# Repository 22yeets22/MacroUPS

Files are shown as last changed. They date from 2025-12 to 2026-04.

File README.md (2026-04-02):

<h1 align="center">
  MacroUPS
  <br>
</h1>

<h4 align="center">
<i>A totally awesome uninterruptible power supply for high speed charging!</i>
</h4>
<br>

### Specs

- 180 Wh LiFePO4 battery - charges an iPhone 16 13 times from 0% to 100%
- 250 watts usb output continuous
- 4 fast charge usb-c ports
- 4 usb-a ports (2 fast charge, 2 slow)
- instantaneous switchover time on power outage

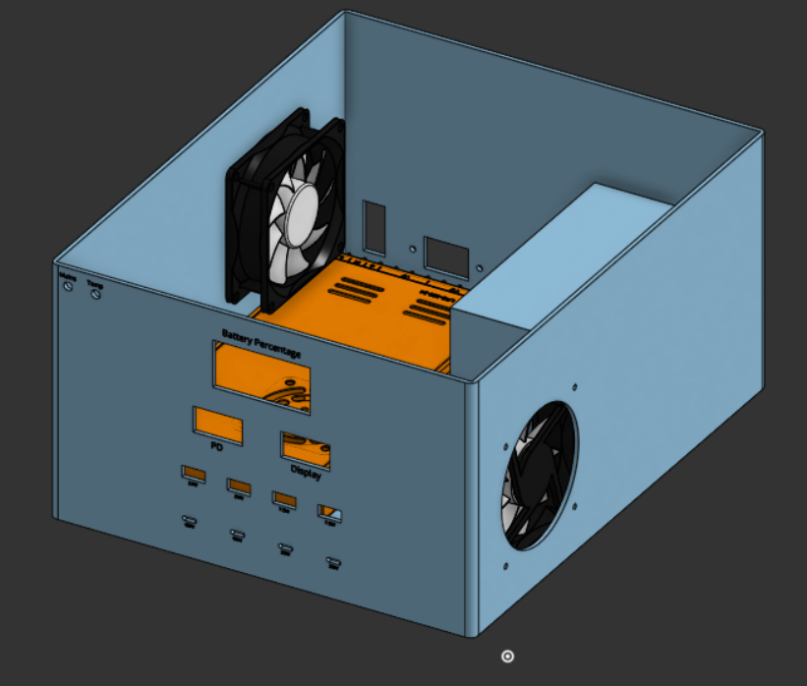
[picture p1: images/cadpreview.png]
CAD preview version 3

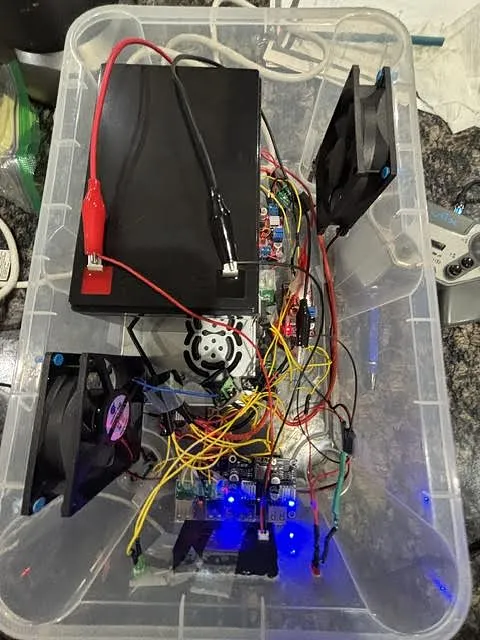
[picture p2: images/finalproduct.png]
Final Product


### Motivation

In our house, we currently charge all our devices in one place, and there aren't enough power outlets. This UPS also acts as backup power in case of an outage, so we can still charge our devices for long after the power is out.

## Parts List

### Power

- 1x of `14awg Wire 30ft`, TYPE 15ft 14awg: [link](https://www.amazon.com/gp/product/B0D969PF5C/) – PRICE $9.98
- 1x of `Power Supply Cable 3-Prong 1.2m`, TYPE USA: [link](https://www.aliexpress.com/item/3256807060355465.html) – PRICE $3.49
- 1x of `IEC320 C14/C13 Panel Socket`, TYPE Type 4: [link](https://www.aliexpress.com/item/3256808473935736.html) – PRICE $1.33
- 1x of `24V 7Ah LiFePO4 Rechargeable Battery with BMS`, TYPE 24V / 7Ah: [link](https://www.amazon.com/gp/product/B0DSRT3BB8/) – PRICE $42.99
- 1x of `MEAN WELL LRS-350-24`, TYPE N/A: [link](https://www.amazon.com/gp/product/B013ETVO12/) – PRICE $28.54

### Power Delivery

- 1x of `PD65W fast charging module (Type-C)`, TYPE 4pcs: [link](https://www.aliexpress.com/item/3256806830457021.html) – PRICE $4.19
- 1x of `PD45W fast charging module (Type-C)`, TYPE 45W: [link](https://www.aliexpress.com/item/3256807318962557.html) – PRICE $1.99
- 2x of `PD30W fast charging module (Type-C)`, TYPE 30W: [link](https://www.aliexpress.com/item/3256807318962557.html) – PRICE $1.95
- 1x of `USB-A breakout female board`, TYPE 5PCS: [link](https://www.aliexpress.com/item/3256807147268432.html) – PRICE $1.24
- 1x of `USB-A QC2.0/3.0 buck converter module`, TYPE 2 Channel: [link](https://www.aliexpress.com/item/3256809395236306.html) – PRICE $1.99
- 4x of `120W USB-C to USB-C fast charging cable`, TYPE Black C-C/2m: [link](https://www.aliexpress.com/item/3256807024111085.html) – PRICE $2.79
- 4x of `120W USB-C to USB-A fast charging cable`, TYPE Black A-C/2m: [link](https://www.aliexpress.com/item/3256807024111085.html) – PRICE $2.21

### Modules

- 1x of `DC-DC adjustable buck converter XL4015`, TYPE HW-083B 4pcs: [link](https://www.aliexpress.com/item/3256806491709950.html) – PRICE $5.07
- 1x of `Battery capacity indicator voltmeter`, TYPE Color Screen/CHINA: [link](https://www.aliexpress.com/item/3256804198482360.html) – PRICE $4.46

#### The Custom Ideal Diode Module (5x) - Order Total (for 5x): $29.12

Check the [ideal diode folder](https://github.com/22yeets22/MacroUPS/tree/main/Ideal%20Diode) for specific BOM, gerber, pickandplace, as well as source files + images.

> [!IMPORTANT]
> There is a folder named `DONOTUSE` with the old versions. The mosfet is the wrong direction in those versions, so please don't use them unless you like expensive paperweights.

Motivation:

- Almost all cheap ideal diode modules commonly found on AliExpress use the XL74610. However, it has voltage drops every half-second because it is groundless and must recharge its capacitor. This is bad for my application, since it would cause voltage fluctuations and constant switching between battery and mains.
- Handles **30a** with big heatsinks on both sides and maybe a thicker copper pour or copper wires on VIN and VOUT)
- Voltage range is up to **40V** limited by the MOSFET.
- 125 C max operating temperature (by components minimum temp), but please keep it cooler than that.

| Schematic | PCB | 3D View |
| --- | --- | --- |
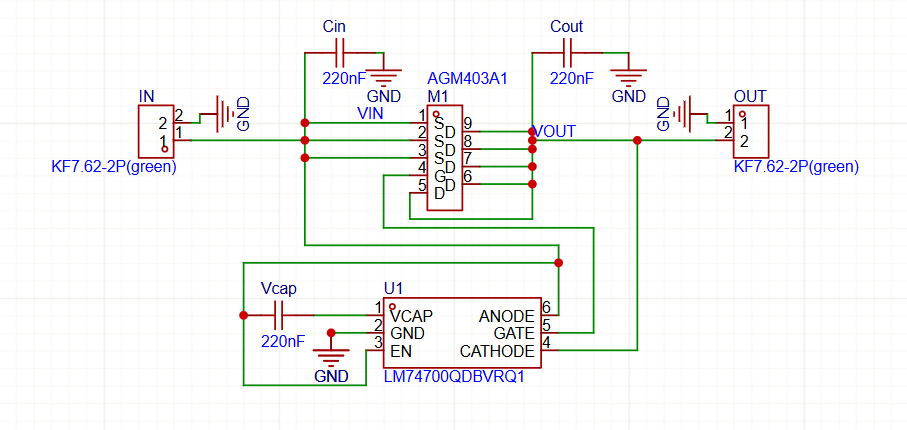
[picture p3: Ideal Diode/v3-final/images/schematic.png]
Schematic
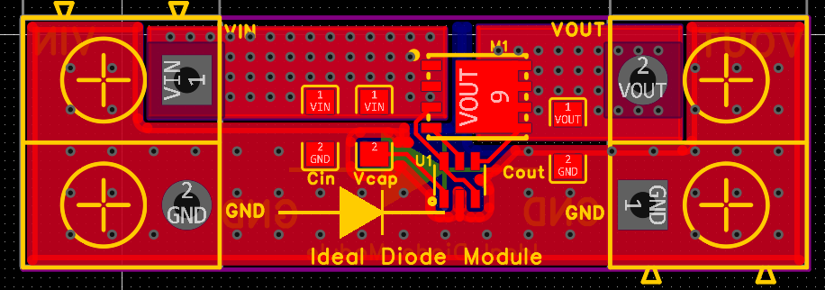
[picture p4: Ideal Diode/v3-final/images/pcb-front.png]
PCB
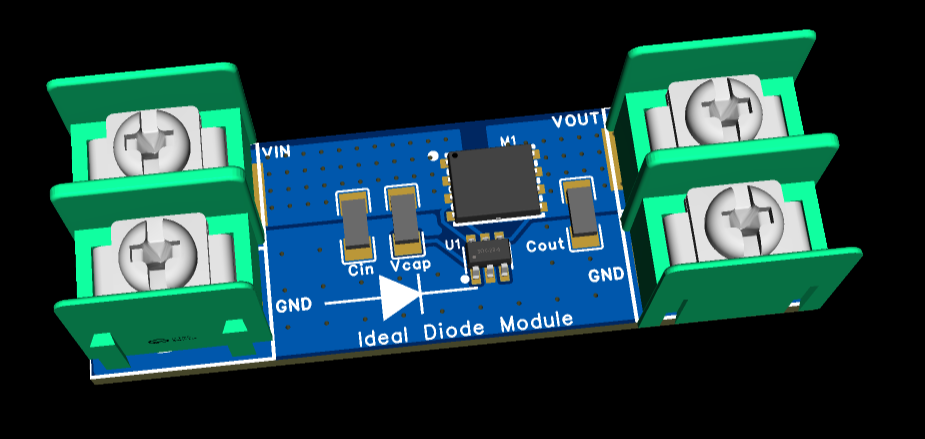
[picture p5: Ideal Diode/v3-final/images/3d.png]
3D
|  |  |  |

### Switches + Fuses

- 1x of `Rocker switch ON-OFF`, TYPE Red 2Pin: [link](https://www.aliexpress.com/item/2255800661582532.html) – PRICE $0.76
- 2x of `SPST waterproof toggle switch`, TYPE N/A: [link](https://www.aliexpress.com/item/3256808459598008.html) – PRICE $2.89
- 2x of `Circuit breaker switch fuse`, TYPE 10A/Other: [link](https://www.aliexpress.com/item/3256805757815979.html) – PRICE $1.63
- 1x of `Circuit breaker switch fuse`, TYPE 15A/Other: [link](https://www.aliexpress.com/item/3256805757815979.html) – PRICE $1.89

### Cooling

- 2x of `12V DC cooling fan`, TYPE 8025/12V: [link](https://www.aliexpress.com/item/3256806120222119.html) – PRICE $3.59
- 3x of `Thermal switch temperature sensor 40C/H`, TYPE 40C/H (Normally Open): [link](https://www.aliexpress.com/item/2251832786193672.html) – PRICE $1.33
- 1x of `Aluminum heatsink 15x15x15mm`, TYPE 15x15x15mm: [link](https://www.aliexpress.com/item/3256803892794950.html) – PRICE $4.38
- 1x of `Aluminum heatsink 8.8x8.8x5mm`, TYPE 8.8x8.8x5mm: [link](https://www.aliexpress.us/item/2251832663311102.html) – PRICE $2.29

## Wiring Diagram

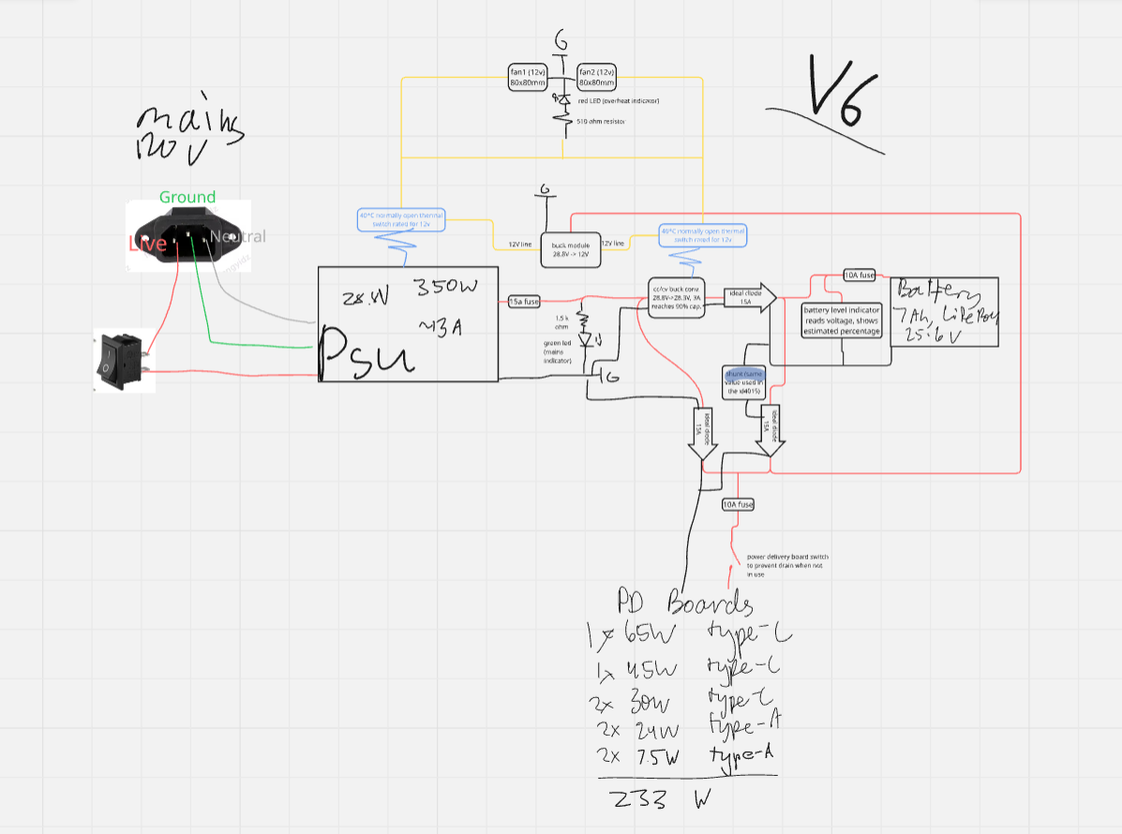
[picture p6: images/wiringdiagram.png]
Wiring diagram version 5


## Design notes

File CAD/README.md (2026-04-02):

## CAD Readme

Quick note, the `MacroUPS3.step` file is the main version. The `USBC Stand.step` file is a file just to hold the usb-c modules in place. The assembly likely differs for everyone, so it may not even be used.

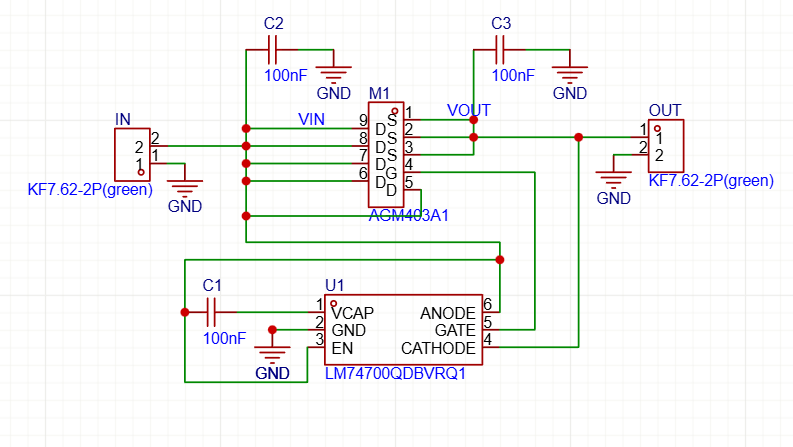
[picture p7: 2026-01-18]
Ideal Diode/DONOTUSE/v2/images/schematic.png

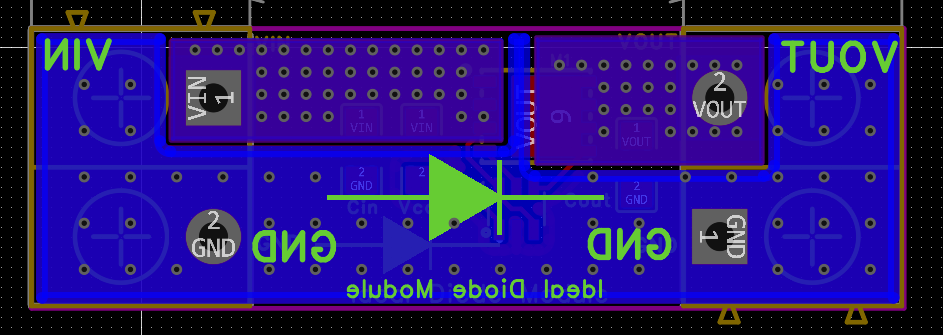
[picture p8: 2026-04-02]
Ideal Diode/v3-final/images/pcb-back.png

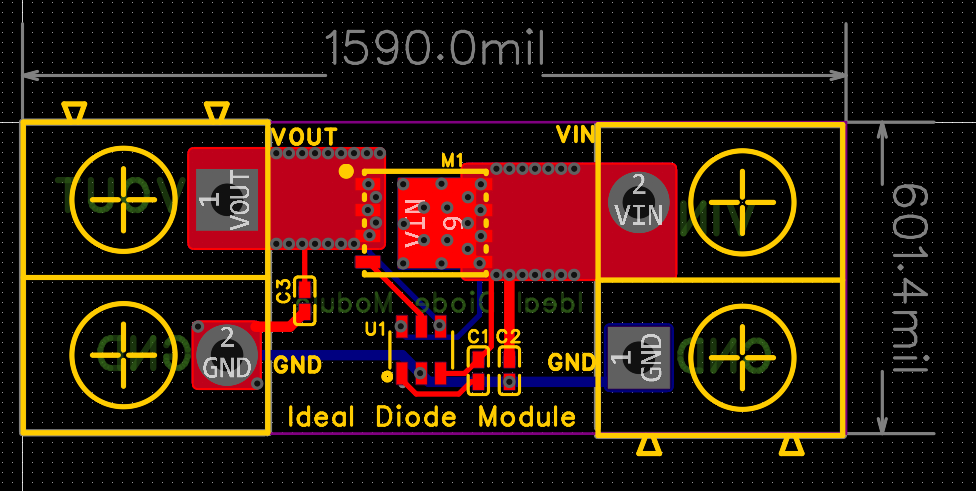
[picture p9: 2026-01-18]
Ideal Diode/DONOTUSE/v2/images/pcb.png

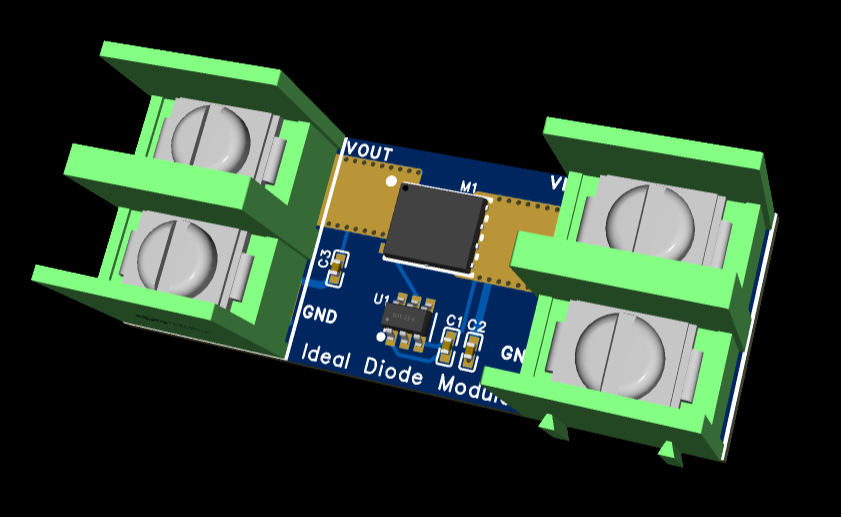
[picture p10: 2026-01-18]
Ideal Diode/DONOTUSE/v2/images/3d.png

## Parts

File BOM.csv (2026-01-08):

Category | Quantity | Part Name | Type | Link | Price
Power | 1 | 14awg Wire 30ft | 15ft 14awg | https://www.amazon.com/gp/product/B0D969PF5C/ | $9.98
Power | 1 | Power Supply Cable 3-Prong 1.2m | USA | https://www.aliexpress.com/item/3256807060355465.html | $3.49
Power | 1 | IEC320 C14/C13 Panel Socket | Type 4 / China Mainland | https://www.aliexpress.com/item/3256808473935736.html | $1.33
Power | 1 | 24V 7Ah LiFePO4 Rechargeable Battery with BMS | 24V / 7Ah | https://www.amazon.com/gp/product/B0DSRT3BB8/ | $42.99
Power | 1 | MEAN WELL LRS-350-24 | N/A | https://www.amazon.com/gp/product/B013ETVO12/ | $28.54
Power Delivery | 1 | PD65W fast charging module (Type-C) | 4pcs | https://www.aliexpress.com/item/3256806830457021.html | $4.19
Power Delivery | 1 | PD45W fast charging module (Type-C) | 45W | https://www.aliexpress.com/item/3256807318962557.html | $1.99
Power Delivery | 2 | PD30W fast charging module (Type-C) | 30W | https://www.aliexpress.com/item/3256807318962557.html | $1.95
Power Delivery | 1 | USB-A breakout female board | 5PCS | https://www.aliexpress.com/item/3256807147268432.html | $1.24
Power Delivery | 1 | USB-A QC2.0/3.0 buck converter module | 2 Channel | https://www.aliexpress.com/item/3256809395236306.html | $1.99
Power Delivery | 3 | 120W USB-C to USB-C fast charging cable | Black C-C/2m | https://www.aliexpress.com/item/3256807024111085.html | $2.79
Power Delivery | 4 | 120W USB-C to USB-A fast charging cable | Black A-C/2m | https://www.aliexpress.com/item/3256807024111085.html | $2.21
Power Delivery | 1 | NNBILI 100W USB C/A charging cable | 100W USB C cable/1m | https://www.aliexpress.com/item/3256806737244284.html | $2.67
Modules | 1 | DC-DC adjustable buck converter XL4015 | HW-083B 4pcs | https://www.aliexpress.com/item/3256806491709950.html | $5.07
Modules | 1 | Battery capacity indicator voltmeter | Color Screen/CHINA | https://www.aliexpress.com/item/3256804198482360.html | $4.46
Modules | 5 | CUSTOM Ideal Diode Module | N/A | https://github.com/22yeets22/MacroUPS/tree/main/Ideal%20Diode | $29.12
Switches + Fuses | 1 | Rocker switch ON-OFF | Red 2Pin | https://www.aliexpress.com/item/2255800661582532.html | $0.76
Switches + Fuses | 2 | SPST waterproof toggle switch | N/A | https://www.aliexpress.com/item/3256808459598008.html | $2.89
Switches + Fuses | 2 | Circuit breaker switch fuse | 10A/Other | https://www.aliexpress.com/item/3256805757815979.html | $1.63
Switches + Fuses | 1 | Circuit breaker switch fuse | 15A/Other | https://www.aliexpress.com/item/3256805757815979.html | $1.89
Cooling | 2 | 12V DC cooling fan | 8025/12V | https://www.aliexpress.com/item/3256806120222119.html | $3.59
Cooling | 3 | Thermal switch temperature sensor 40C/H | 40C/H (Normally Open) | https://www.aliexpress.com/item/2251832786193672.html | $1.33
Cooling | 1 | Aluminum heatsink 15x15x15mm | 15x15x15mm | https://www.aliexpress.com/item/3256803892794950.html | $4.38
Cooling | 1 | Aluminum heatsink 8.8x8.8x5mm | 8.8x8.8x5mm | https://www.aliexpress.us/item/2251832663311102.html | $2.29

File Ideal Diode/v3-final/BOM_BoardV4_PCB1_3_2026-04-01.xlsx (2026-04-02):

No. | Quantity | Comment | Designator | Footprint | Value | Manufacturer Part | Manufacturer | Supplier Part | Supplier
1 | 3 | 220nF | Cin,Cout,Vcap | C1206 | 220nF | CC1206KKX7R0BB224 | YAGEO(国巨) | C113892 | LCSC
2 | 2 | KF7.62-2P(green) | IN,OUT | CONN-TH_2P-P7.62_KEFA_KF7.62-2P |  | KF7.62-2P(green) | KEFA(科发) | C5173665 | LCSC
3 | 1 | AGM403A1 | M1 | DFN-8_L5.8-W4.9-P1.27-LS6.0-BL-1 |  | AGM403A1 | AGMSEMI(芯控源) | C5184861 | LCSC
4 | 1 | LM74700QDBVRQ1 | U1 | SOT-23-6_L2.9-W1.6-P0.95-LS2.8-BL |  | LM74700QDBVRQ1 | TI(德州仪器) | C2941042 | LCSC

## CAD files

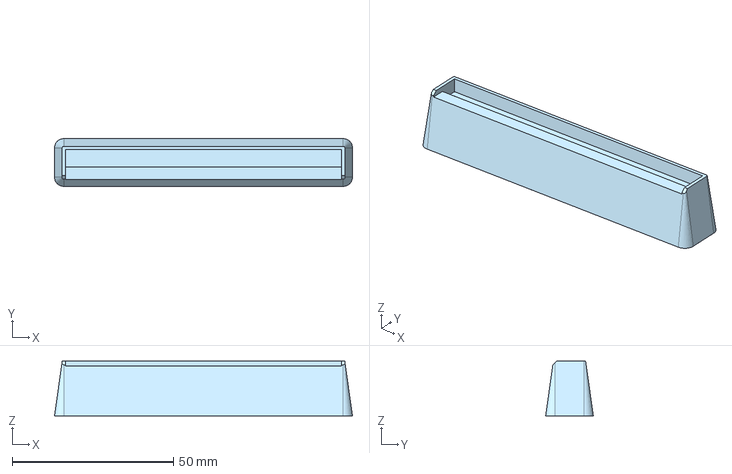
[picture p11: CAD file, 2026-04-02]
CAD/USBC Stand.step
92.3 x 14.8 x 17.0 mm

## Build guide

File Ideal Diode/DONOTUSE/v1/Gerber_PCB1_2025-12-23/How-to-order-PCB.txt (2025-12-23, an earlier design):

How to Order PCB

Please refer to:
https://prodocs.easyeda.com/en/pcb/order-order-pcb/index.html

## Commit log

2025-12-14 add cad
2025-12-14 Rename Screenshot 2025-12-14 135559.png to wiringdiagram.png
2025-12-15 Add wiring diagram to README
    Added a wiring diagram section with an image to the README.
2025-12-15 Revise BOM with new categories and parts
    Updated BOM.csv to include new categories and additional parts with details.
    [BOM.csv]
2025-12-15 Fix BOM.csv formatting and header alignment
    [BOM.csv]
2025-12-18 New bom
    [BOM.csv]
2025-12-18 Rename Screenshot 2025-12-17 204821.png to wiringdiagram.png
2025-12-18 Add USB-A breakout board to parts list
2025-12-18 add usb-a breakout board (fix formatting)
    Added a parts list for the MacroUPS project.
2025-12-18 new cad files
2025-12-18 Revise USB buck converter module type in README
    Updated parts list to reflect changes in USB buck converter module type.
2025-12-18 Modify USB QC2.0/3.0 buck converter module details (fix bom)
    Updated the USB QC2.0/3.0 buck converter module from 4 Channel to 2 Channel.
    [BOM.csv]
2025-12-18 add ideal diode pcb stuff
    [BOM.xlsx, PickAndPlace.xlsx]
2025-12-18 Update ideal diode module entry in BOM.csv
    [BOM.csv]
2025-12-18 Add Custom Ideal Diode Module section to README
    Added section for the Custom Ideal Diode Module with links.
2025-12-23 Update link text for ideal diode module section
2025-12-23 Rename Screenshot 2025-12-23 102950.png to schematic.png
2025-12-23 Revise power delivery module specifications
    Updated the list of power delivery modules in the README.
2025-12-23 update ideal diode gerber, pickandplace, bom, updated BOM.csv, added ideal diode source files, updated readme with also schematic
    [BOM.csv, BOM.xlsx, BOM_Board1_PCB1_2025-12-23.xlsx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]
2025-12-23 Update quantity for CUSTOM IDEAL DIODE MODULE
    [BOM.csv]
2025-12-23 Update Custom Ideal Diode Module section in README
2025-12-23 Uploaded step CAD
2025-12-23 Update quantity and order total for ideal diode module
2025-12-23 Add category and price columns to BOM.csv
    Updated BOM.csv to include category and price information for each part.
    [BOM.csv]
2025-12-23 Revise order total for Custom Ideal Diode Module
    Updated the order total for the Custom Ideal Diode Module section.
2025-12-23 add folder for ideal diode images
2025-12-23 unzip gerber???
    [Drill_PTH_Through.DRL, Drill_PTH_Through_Via.DRL, Gerber_BoardOutlineLayer.GKO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]
2026-01-01 Update parts list and add motivation for ideal diode module
    Added new power supply and socket details to the parts list, along with motivation for the custom ideal diode module.
2026-01-01 Enhance README with motivation for ideal diode module
    Added motivation section for the custom ideal diode module, explaining its advantages over common alternatives and its specifications.
2026-01-01 Update BOM.csv with new power supply items
    Replaced two power-related items with new products and updated their details.
    [BOM.csv]
2026-01-01 upd cad step file, upd images: cad preview wiring diagram
2026-01-04 Fix link type for IEC320 C14/C13 Panel Socket
2026-01-08 Fix link for 8.8x8.8x5mm aluminum heatsink
    Updated the link for the 8.8x8.8x5mm aluminum heatsink.
2026-01-08 Change URL for Aluminum heatsink in BOM.csv
    Updated the URL for the Aluminum heatsink 8.8x8.8x5mm.
    [BOM.csv]
2026-01-08 Update motivation details for ideal diode module
    Revised motivation section for the ideal diode module to clarify performance and specifications.
2026-01-18 NEW IDEAL DIODE
    [BOM_Board1_PCB1_2025-12-23.xlsx, BOM_BoardV2_PCB1_1_2026-01-17.xlsx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]
2026-04-02 schematic v6 (with shunt), show final product, usb stand, new ideal diode module, new readme
    [BOM_Board1_PCB1_2025-12-23.xlsx, BOM_BoardV2_PCB1_1_2026-01-17.xlsx, BOM_BoardV4_PCB1_3_2026-04-01.xlsx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]
2026-04-02 schematic v6 (with shunt), show final product, usb stand, new ideal diode module, new readme
    update of initial commit, small fixed to ideal diode images in readme
